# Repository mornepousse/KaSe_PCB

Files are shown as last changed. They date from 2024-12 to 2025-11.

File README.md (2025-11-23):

# KaSe – Keyboard Dev Kit

This repository contains the KiCad project and resources for the KaSe keyboard, a compact, column-staggered layout inspired by the Atreus62.

## Project overview

KaSe is designed to be:
- ergonomic, with a compact and column-oriented layout;
- DIY‑friendly, using a single PCB and common components;
- easy to customize (firmware, keymap, and hardware variations).

## Photos

### Main view

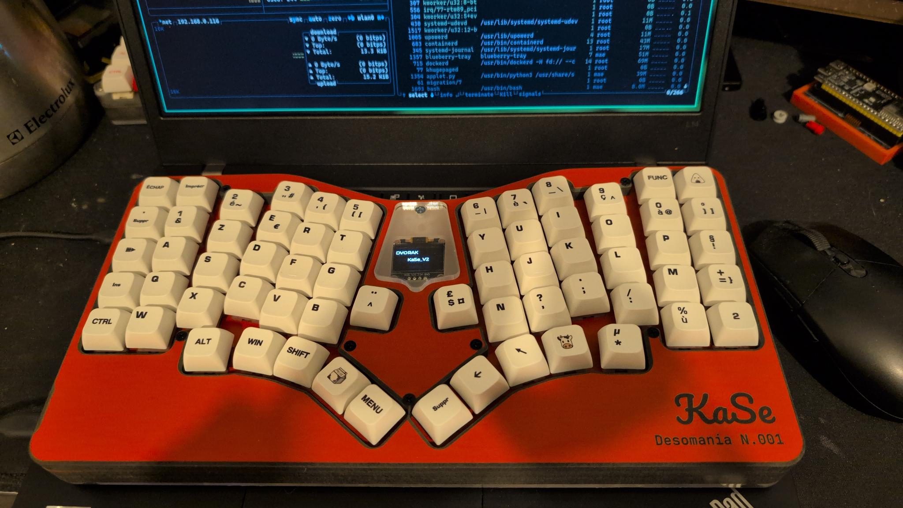
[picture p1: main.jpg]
Main view


Assembled KaSe keyboard with switches and keycaps installed. This picture gives an overview of the final form factor and layout.

### Top view – PCB

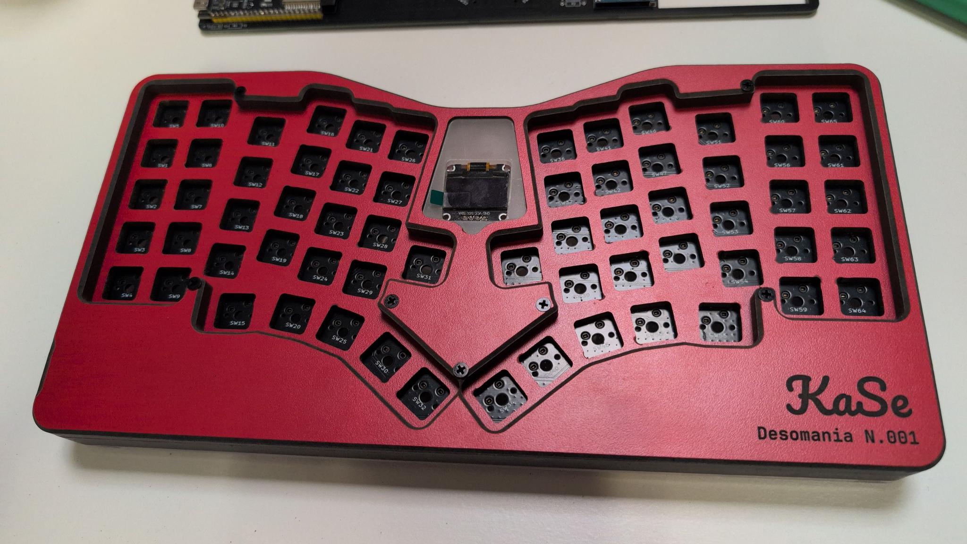
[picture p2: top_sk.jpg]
Top view


Top‑side view of the PCB showing:
- board outline,
- switch positions,
- locations of main components and connectors.

### Routing details

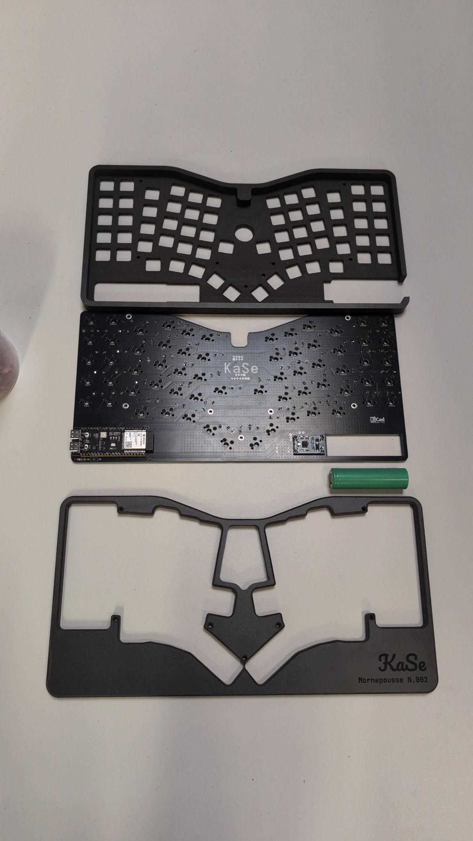
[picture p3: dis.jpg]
Routing details


Close‑up of the PCB routing, highlighting:
- main traces and vias,
- matrix rows/columns and power traces,
- silkscreen details and graphics.

### Bottom view

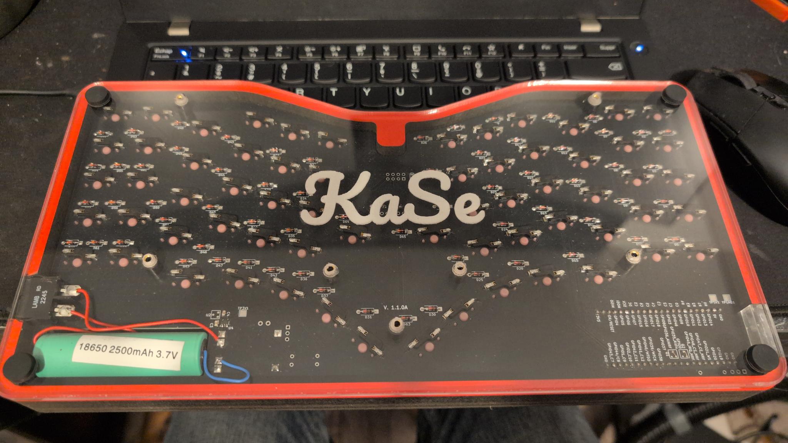
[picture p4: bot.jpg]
Bottom view


Underside of the PCB or assembly, showing:
- copper pours and ground planes,
- pads and vias,
- possible logos and fabrication information.

## Repository structure

- `Old/` – Legacy Atreus62 project kept for reference.
- `V2/KaSe/` – Current KaSe PCB KiCad project (schematic, PCB, libraries, production files).
- `V2/schematic.crv3d` – 3D/MCAD resources related to the project.
- `README.md` – Project documentation (this file).

## Main KiCad files (KaSe)

Inside `V2/KaSe/`:
- `KaSe.kicad_sch` / `KaSe.sch` – keyboard schematic.
- `KaSe.kicad_pcb` – PCB layout for KaSe.
- `Gerbers/` – production files for PCB manufacturing.
- `footprints.pretty/`, `key.pretty/`, `MaeLid.pretty/`, `PMW3360.pretty/`, `NRF24L01_/` – custom footprints and symbols used in the design.
- `KaSe.kicad_pro` / `KaSe.pro` – KiCad project files.

## Opening the project in KiCad

1. Clone the repository:
	```bash
	git clone https://github.com/mornepousse/KaSe_PCB.git
	cd KaSe_PCB
	```
2. Open KiCad.
3. Open the project file `V2/KaSe/KaSe.kicad_pro`.
4. From KiCad, open the schematic (`KaSe.kicad_sch`) and the PCB (`KaSe.kicad_pcb`).

## PCB fabrication

Gerber files for manufacturing are located in `V2/KaSe/Gerbers/`.

Typical steps:
- Zip the contents of `V2/KaSe/Gerbers/`.
- Upload the ZIP archive to your PCB manufacturer (e.g. JLCPCB).
- Check the PCB preview and confirm the order.

## License and usage

Unless otherwise specified in this repository, this project is provided for personal, experimental, and educational use.  
Please credit the original project if you publish or derive from this design.

---

# KaSe – Kit de développement de clavier

Ce dépôt contient le projet KiCad et les ressources nécessaires pour le clavier KaSe, un clavier compact à colonnes inspiré de l’Atreus62.

## Présentation du projet

Le KaSe est conçu pour être :
- ergonomique, avec une disposition compacte et en colonnes ;
- adapté au DIY, avec un seul PCB et des composants courants ;
- facilement personnalisable (firmware, disposition des touches, variantes matérielles).

## Photos

### Vue principale

Vue principale

Clavier KaSe assemblé avec les switchs et les keycaps installés. Cette photo donne une idée du format final et de la disposition.

### Vue du dessus – PCB

Vue du dessus – PCB

Vue du PCB côté composants montrant :
- le contour de la carte,
- l’implantation des switchs,
- les emplacements des principaux composants et connecteurs.

### Détails du routage

Détails du routage

Gros plan sur le routage du PCB mettant en avant :
- les pistes et vias principaux,
- les lignes du matrix (rangées/colonnes) et l’alimentation,
- les détails de sérigraphie et éléments graphiques.

### Vue du dessous

Vue du dessous

Vue de l’arrière du PCB ou de l’assemblage, montrant :
- les plans de masse et surfaces cuivrées,
- les pastilles et vias,
- les logos et informations de fabrication éventuels.

## Structure du dépôt

- `Old/` – Ancien projet Atreus62 conservé comme référence.
- `V2/KaSe/` – Projet KiCad actuel du PCB KaSe (schéma, PCB, bibliothèques, fichiers de production).
- `V2/schematic.crv3d` – Ressources 3D/CAO liées au projet.
- `README.md` – Documentation du projet (ce fichier).

## Fichiers KiCad principaux (KaSe)

Dans `V2/KaSe/` :
- `KaSe.kicad_sch` / `KaSe.sch` – schémas du clavier.
- `KaSe.kicad_pcb` – routage du PCB KaSe.
- `Gerbers/` – fichiers de production pour la fabrication du PCB.
- `footprints.pretty/`, `key.pretty/`, `MaeLid.pretty/`, `PMW3360.pretty/`, `NRF24L01_/` – bibliothèques de footprints et symboles spécifiques.
- `KaSe.kicad_pro` / `KaSe.pro` – fichiers de projet KiCad.

## Ouvrir le projet dans KiCad

1. Cloner le dépôt :
	```bash
	git clone https://github.com/mornepousse/KaSe_PCB.git
	cd KaSe_PCB
	```
2. Ouvrir KiCad.
3. Charger le projet `V2/KaSe/KaSe.kicad_pro`.
4. Depuis KiCad, ouvrir le schéma (`KaSe.kicad_sch`) puis le PCB (`KaSe.kicad_pcb`).

## Fabrication du PCB

Les fichiers Gerber sont dans `V2/KaSe/Gerbers/`.

Étapes typiques :
- Compresser le contenu de `V2/KaSe/Gerbers/` dans une archive `.zip`.
- Importer cette archive sur le site de ton fabricant de PCB (par ex. JLCPCB).
- Vérifier la prévisualisation puis valider la commande.

## Licence et utilisation

Sauf indication contraire dans ce dépôt, ce projet est fourni pour un usage personnel, expérimental et éducatif.  
Merci de mentionner la source si tu republies ou dérives ce design.

Mae Keyboard DEV Kit version

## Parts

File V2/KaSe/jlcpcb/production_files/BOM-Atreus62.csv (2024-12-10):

Comment | Designator | Footprint | LCSC
10K | R15,R16,R17,R18,R20,R4,R5,R6 | R_0402_1005Metric | C11702
100nF | C15,C2,C5,C6,C8 | C_0402_1005Metric | C1525
TPS63031DSK | U9 | WSON-10-1EP_2.5x2.5mm_P0.5mm_EP1.2x2mm | C15516
1uF | C1,C10,C11,C12,C19,C20,C22,C28,C3,C4,C7,C9 | C_0402_1005Metric | C15525
22pF | C13,C14 | C_0402_1005Metric | C1555
680K | R1 | R_0402_1005Metric | C158991
150K | R9 | R_0603_1608Metric_Pad0.98x0.95mm_HandSolder | C22807
220K | R8 | R_0603_1608Metric_Pad0.98x0.95mm_HandSolder | C22961
GREEN | LED1 | LED_0805_2012Metric | C2297
470K | R10,R11 | R_0603_1608Metric_Pad0.98x0.95mm_HandSolder | C23178
4.7uF | C17,C27 | C_0402_1005Metric | C23733
22 | R14,R2,R3,R7 | R_0402_1005Metric | C25092
5k1 | R12,R13 | R_0402_1005Metric | C25905
40MHz | Y1 | Crystal_SMD_3225-4Pin_3.2x2.5mm | C2875582
BQ25611D | U1 | Texas_RTW_WQFN-24-1EP_4x4mm_P0.5mm_EP2.7x2.7mm_ThermalVias | C2892871
ESP32-S3 | U2 | QFN-56-1EP_7x7mm_P0.4mm_EP5.6x5.6mm | C2913194
USB_C_Plug_USB2.0 | P1 | USB_C_Receptacle_GCT_USB4105-xx-A_16P_TopMnt_Horizontal | C2936185
10pF | C16,C18 | C_0402_1005Metric | C32949
Antenna_Shield | AE2 | ipx | C496552
1.5 μH | L1,L2 | L_Cenker_CKCS3012 | C75110
DIODE | D1,D10,D11,D12,D13,D14,D15,D16,D17,D18,D19,D2,D20,D21,D22,D23,D24,D25,D26,D27,D28,D29,D3,D30,D31,D33,D34,D35,D36,D37,D38,D39,D4,D40,D41,D42,D43,D44,D45,D46,D47,D48,D49,D5,D50,D51,D52,D53,D54,D55,D56,D57,D58,D59,D6,D60,D61,D62,D63,D64,D65,D7,D8,D9 | D_SOD-123 | C8598
W25Q128JVS | U4 | SOIC-8_5.23x5.23mm_P1.27mm | C97521
1nH | L3 | R_0402_1005Metric | C97981
Conn_01x10_Pin | J4 | PinSocket_2x05_P1.27mm_Vertical
TestPoint_Loop_D3.80mm_Drill2.8mm | HS8 | TestPoint_Loop_D3.80mm_Drill2.8mm
SWITCH_PUSH | SW61 | SW_Cherry_MX_1.00u_PCB
SWITCH_PUSH | SW50 | SW_Cherry_MX_1.00u_PCB
SWITCH_PUSH | SW21 | SW_Cherry_MX_1.00u_PCB
TestPoint_Loop_D3.80mm_Drill2.8mm | HS7 | TestPoint_Loop_D3.80mm_Drill2.8mm
Conn_01x10_Pin | J2 | PinHeader_2x05_P2.54mm_Vertical
SWITCH_PUSH | SW63 | SW_Cherry_MX_1.00u_PCB
SWITCH_PUSH | SW64 | SW_Cherry_MX_1.00u_PCB
SWITCH_PUSH | SW7 | SW_Cherry_MX_1.00u_PCB
SWITCH_PUSH | SW60 | SW_Cherry_MX_1.00u_PCB
SWITCH_PUSH | SW55 | SW_Cherry_MX_1.00u_PCB
SWITCH_PUSH | SW9 | SW_Cherry_MX_1.00u_PCB
SWITCH_PUSH | SW17 | SW_Cherry_MX_1.00u_PCB
SWITCH_PUSH | SW10 | SW_Cherry_MX_1.00u_PCB
TestPoint_Loop_D3.80mm_Drill2.8mm | HS2 | TestPoint_Loop_D3.80mm_Drill2.8mm
SWITCH_PUSH | SW51 | SW_Cherry_MX_1.00u_PCB
SWITCH_PUSH | SW65 | SW_Cherry_MX_1.00u_PCB
SWITCH_PUSH | SW38 | SW_Cherry_MX_1.00u_PCB
Conn_01x02 | J1 | D_T-1_P2.54mm_Vertical_AnodeUp
SWITCH_PUSH | SW25 | SW_Cherry_MX_1.00u_PCB
SWITCH_PUSH | SW23 | SW_Cherry_MX_1.00u_PCB
TestPoint_Loop_D3.80mm_Drill2.8mm | HS3 | TestPoint_Loop_D3.80mm_Drill2.8mm
SWITCH_PUSH | SW48 | SW_Cherry_MX_1.00u_PCB
TestPoint_Loop_D3.80mm_Drill2.8mm | HS5 | TestPoint_Loop_D3.80mm_Drill2.8mm
SWITCH_PUSH | SW14 | SW_Cherry_MX_1.00u_PCB
SWITCH_PUSH | SW52 | SW_Cherry_MX_1.00u_PCB
SWITCH_PUSH | SW62 | SW_Cherry_MX_1.00u_PCB
SWITCH_PUSH | SW54 | SW_Cherry_MX_1.00u_PCB
SWITCH_PUSH | SW24 | SW_Cherry_MX_1.00u_PCB
TestPoint_Loop_D3.80mm_Drill2.8mm | HS1 | TestPoint_Loop_D3.80mm_Drill2.8mm
SWITCH_PUSH | SW45 | SW_Cherry_MX_1.00u_PCB
SWITCH_PUSH | SW37 | SW_Cherry_MX_1.00u_PCB
SWITCH_PUSH | SW56 | SW_Cherry_MX_1.00u_PCB
SWITCH_PUSH | SW53 | SW_Cherry_MX_1.00u_PCB
SWITCH_PUSH | SW28 | SW_Cherry_MX_1.00u_PCB
SWITCH_PUSH | SW8 | SW_Cherry_MX_1.00u_PCB
SWITCH_PUSH | SW22 | SW_Cherry_MX_1.00u_PCB
TestPoint_Loop_D3.80mm_Drill2.8mm | HS6 | TestPoint_Loop_D3.80mm_Drill2.8mm
SWITCH_PUSH | SW19 | SW_Cherry_MX_1.00u_PCB
SWITCH_PUSH | SW13 | SW_Cherry_MX_1.00u_PCB
SWITCH_PUSH | SW2 | SW_Cherry_MX_1.00u_PCB
SWITCH_PUSH | SW43 | SW_Cherry_MX_1.00u_PCB
SWITCH_PUSH | SW57 | SW_Cherry_MX_1.00u_PCB
SWITCH_PUSH | SW1 | SW_Cherry_MX_1.00u_PCB
SWITCH_PUSH | SW29 | SW_Cherry_MX_1.00u_PCB
SWITCH_PUSH | SW42 | SW_Cherry_MX_1.00u_PCB
SWITCH_PUSH | SW49 | SW_Cherry_MX_1.00u_PCB
SWITCH_PUSH | SW44 | SW_Cherry_MX_1.00u_PCB
SWITCH_PUSH | SW18 | SW_Cherry_MX_1.00u_PCB
kicad | HS9 | KiCad-Logo2_5mm_SilkScreen
SWITCH_PUSH | SW11 | SW_Cherry_MX_1.00u_PCB
SWITCH_PUSH | SW58 | SW_Cherry_MX_1.00u_PCB
SWITCH_PUSH | SW32 | SW_Cherry_MX_1.00u_PCB
SWITCH_PUSH | SW15 | SW_Cherry_MX_1.00u_PCB
SWITCH_PUSH | SW39 | SW_Cherry_MX_1.00u_PCB
SWITCH_PUSH | SW33 | SW_Cherry_MX_1.00u_PCB
SWITCH_PUSH | SW41 | SW_Cherry_MX_1.00u_PCB
SWITCH_PUSH | SW20 | SW_Cherry_MX_1.00u_PCB
SWITCH_PUSH | SW5 | SW_Cherry_MX_1.00u_PCB
SWITCH_PUSH | SW59 | SW_Cherry_MX_1.00u_PCB
SWITCH_PUSH | SW6 | SW_Cherry_MX_1.00u_PCB
SWITCH_PUSH | SW27 | SW_Cherry_MX_1.00u_PCB
SWITCH_PUSH | SW16 | SW_Cherry_MX_1.00u_PCB
SWITCH_PUSH | SW40 | SW_Cherry_MX_1.00u_PCB
SWITCH_PUSH | SW47 | SW_Cherry_MX_1.00u_PCB
SWITCH_PUSH | SW46 | SW_Cherry_MX_1.00u_PCB
SWITCH_PUSH | SW34 | SW_Cherry_MX_1.00u_PCB
SWITCH_PUSH | SW26 | SW_Cherry_MX_1.00u_PCB
Conn_02x04 | J3 | PinHeader_2x04_P2.54mm_Vertical
SWITCH_PUSH | SW36 | SW_Cherry_MX_1.00u_PCB
SWITCH_PUSH | SW30 | SW_Cherry_MX_1.00u_PCB
SWITCH_PUSH | SW31 | SW_Cherry_MX_1.00u_PCB
SWITCH_PUSH | SW4 | SW_Cherry_MX_1.00u_PCB
SWITCH_PUSH | SW12 | SW_Cherry_MX_1.00u_PCB
SWITCH_PUSH | SW3 | SW_Cherry_MX_1.00u_PCB
SERLINK | X1 | CON_SER9
TestPoint | TP1 | TestPoint_Pad_D1.0mm
Conn_02x03 | J5 | PinSocket_2x03_P1.27mm_Vertical

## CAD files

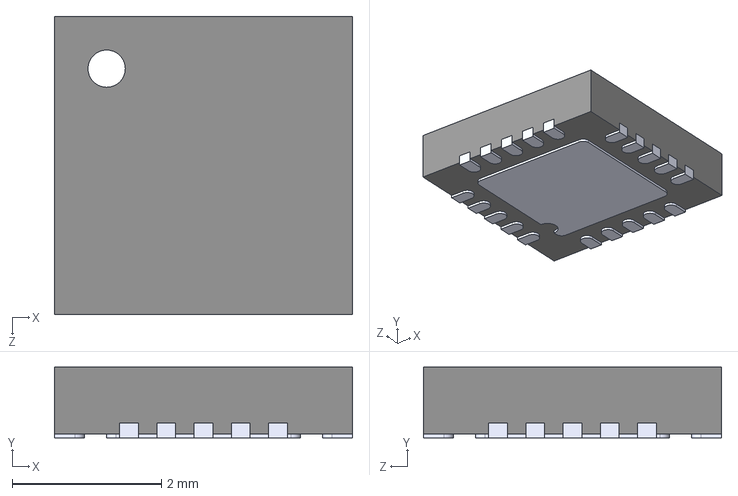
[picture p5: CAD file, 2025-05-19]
Mae_Keyboard_Dev_Kit/NRF24L01_/NRF24L01_.step
4.00 x 0.95 x 4.00 mm

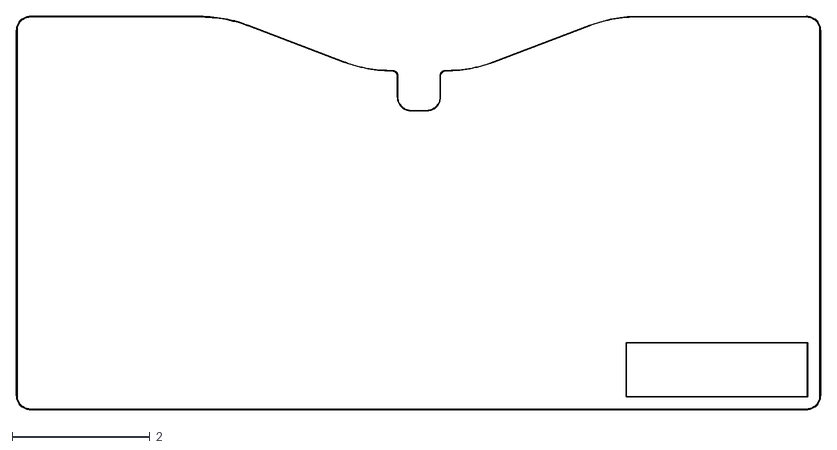
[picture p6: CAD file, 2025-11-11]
V2/KaSe/DXF/KaSe-Edge_Cuts.dxf
11.7 x 5.72

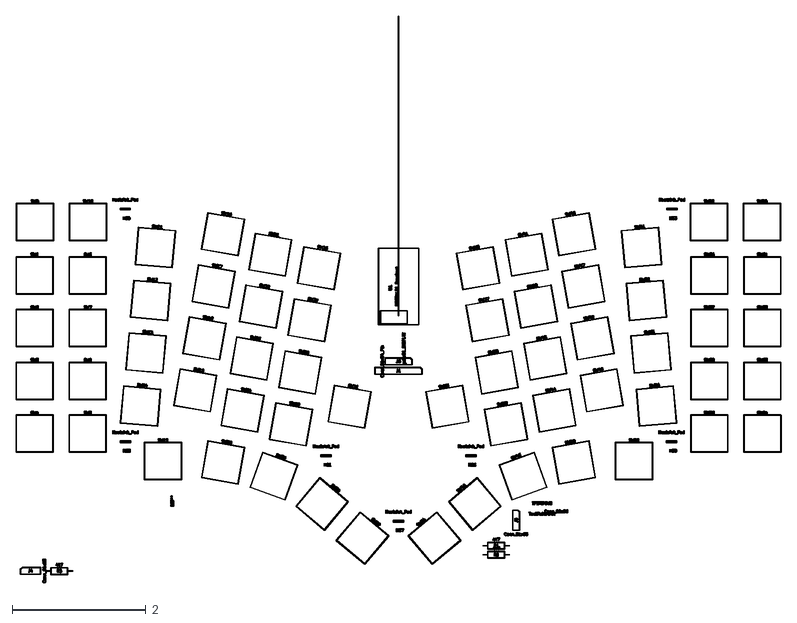
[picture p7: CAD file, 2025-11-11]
V2/KaSe/DXF/KaSe-F_Fab.dxf
11.4 x 8.45

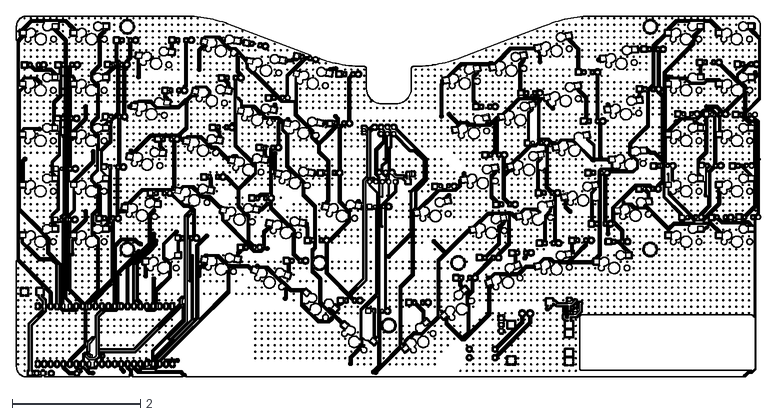
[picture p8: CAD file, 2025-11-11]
V2/KaSe/DXF/KaSe-B_Cu.dxf
11.6 x 5.63

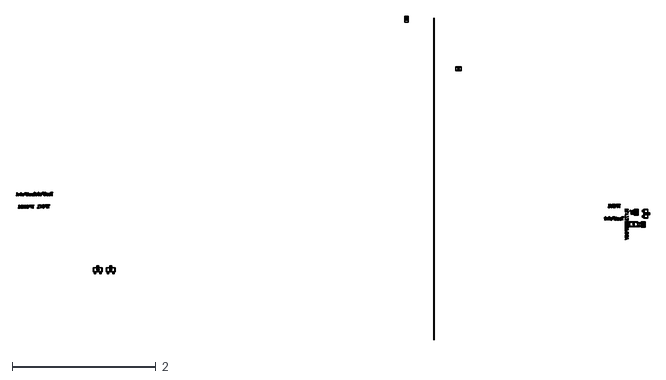
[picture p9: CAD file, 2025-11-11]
V2/KaSe/DXF/KaSe-B_Fab.dxf
8.82 x 4.50

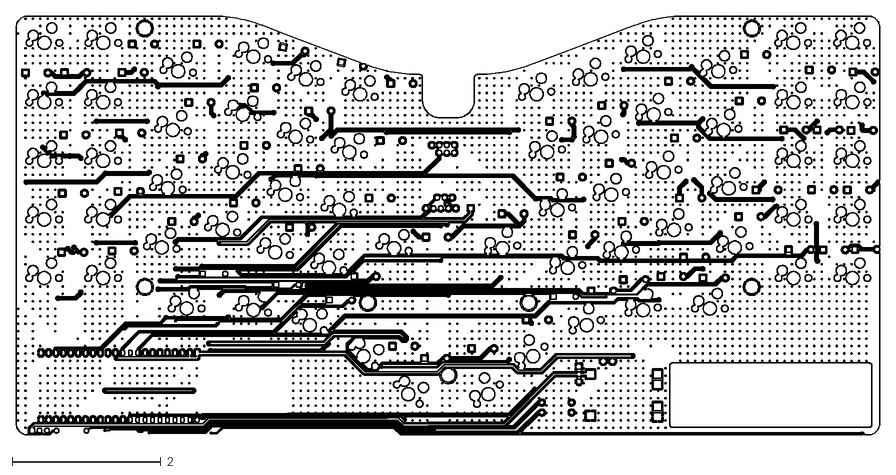
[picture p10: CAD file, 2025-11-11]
V2/KaSe/DXF/KaSe-F_Cu.dxf
11.6 x 5.63

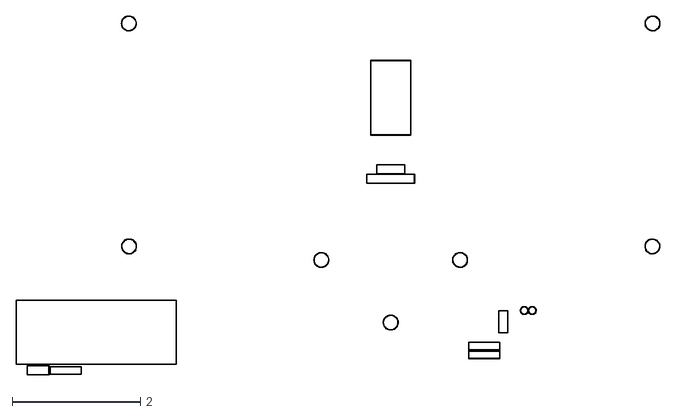
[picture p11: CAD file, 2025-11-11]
V2/KaSe/DXF/KaSe-F_Courtyard.dxf
10.0 x 5.59

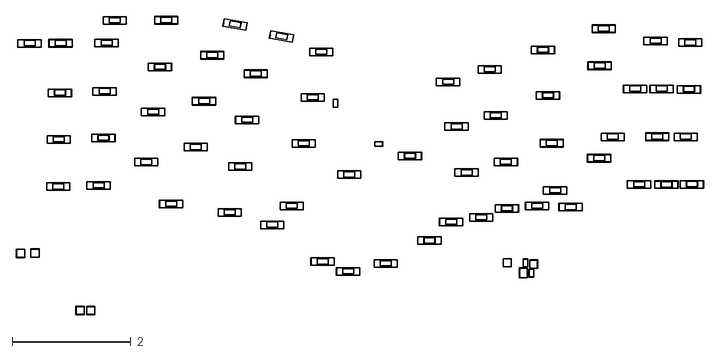
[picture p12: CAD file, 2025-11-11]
V2/KaSe/DXF/KaSe-B_Courtyard.dxf
11.6 x 5.01

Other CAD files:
V2/KaSe/DXF/KaSe-F_Adhesive.dxf
V2/KaSe/DXF/KaSe-B_Adhesive.dxf
V2/KaSe/DXF/KaSe-B_Mask.dxf
V2/KaSe/DXF/KaSe-B_Paste.dxf
V2/KaSe/DXF/KaSe-B_Silkscreen.dxf
V2/KaSe/DXF/KaSe-F_Mask.dxf
V2/KaSe/DXF/KaSe-F_Paste.dxf
V2/KaSe/DXF/KaSe-F_Silkscreen.dxf

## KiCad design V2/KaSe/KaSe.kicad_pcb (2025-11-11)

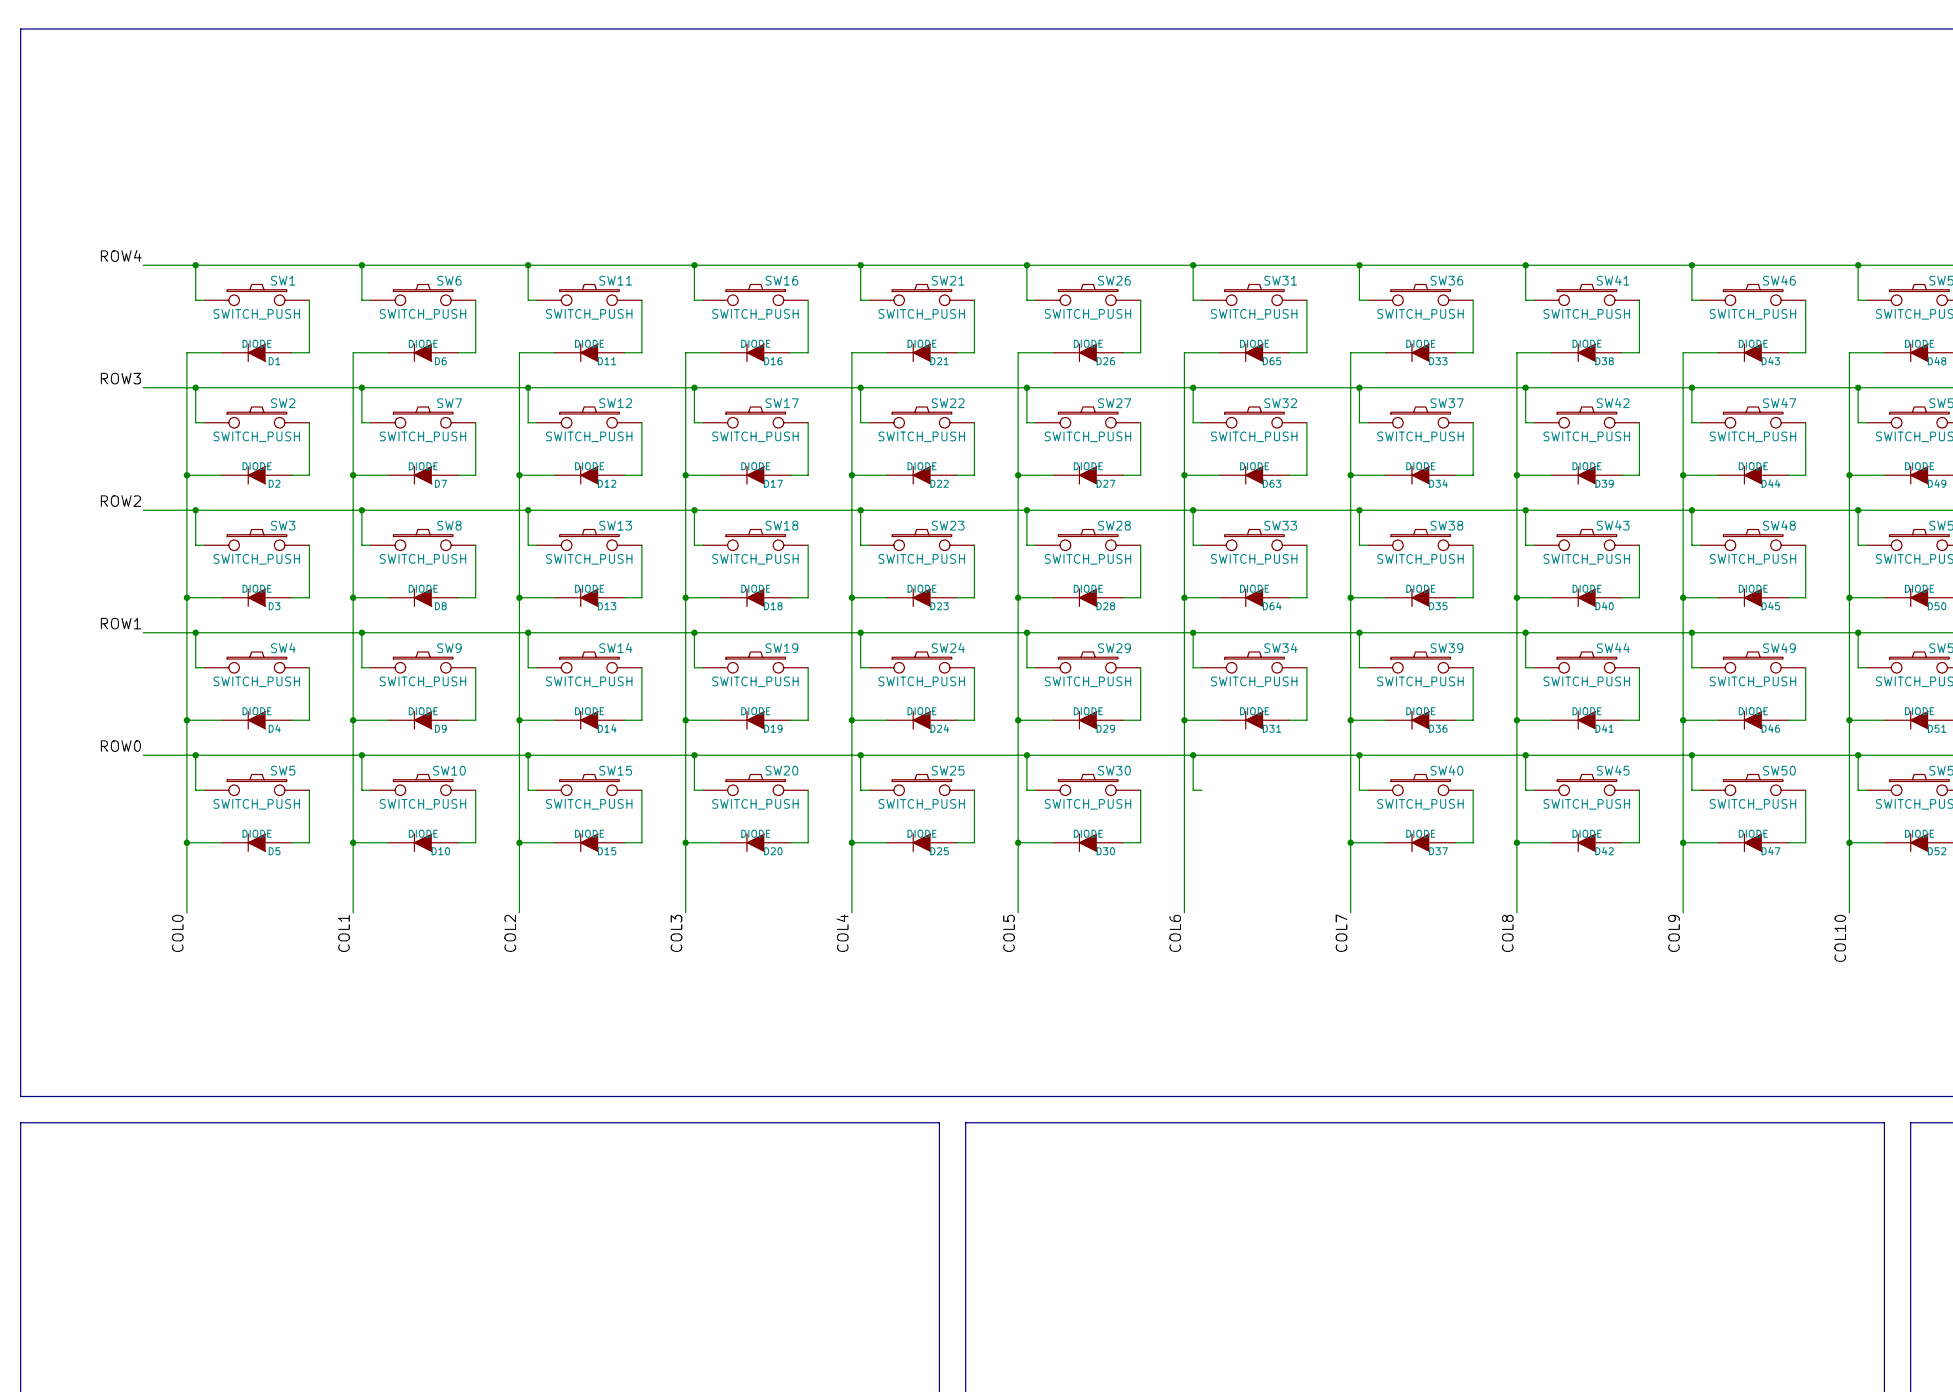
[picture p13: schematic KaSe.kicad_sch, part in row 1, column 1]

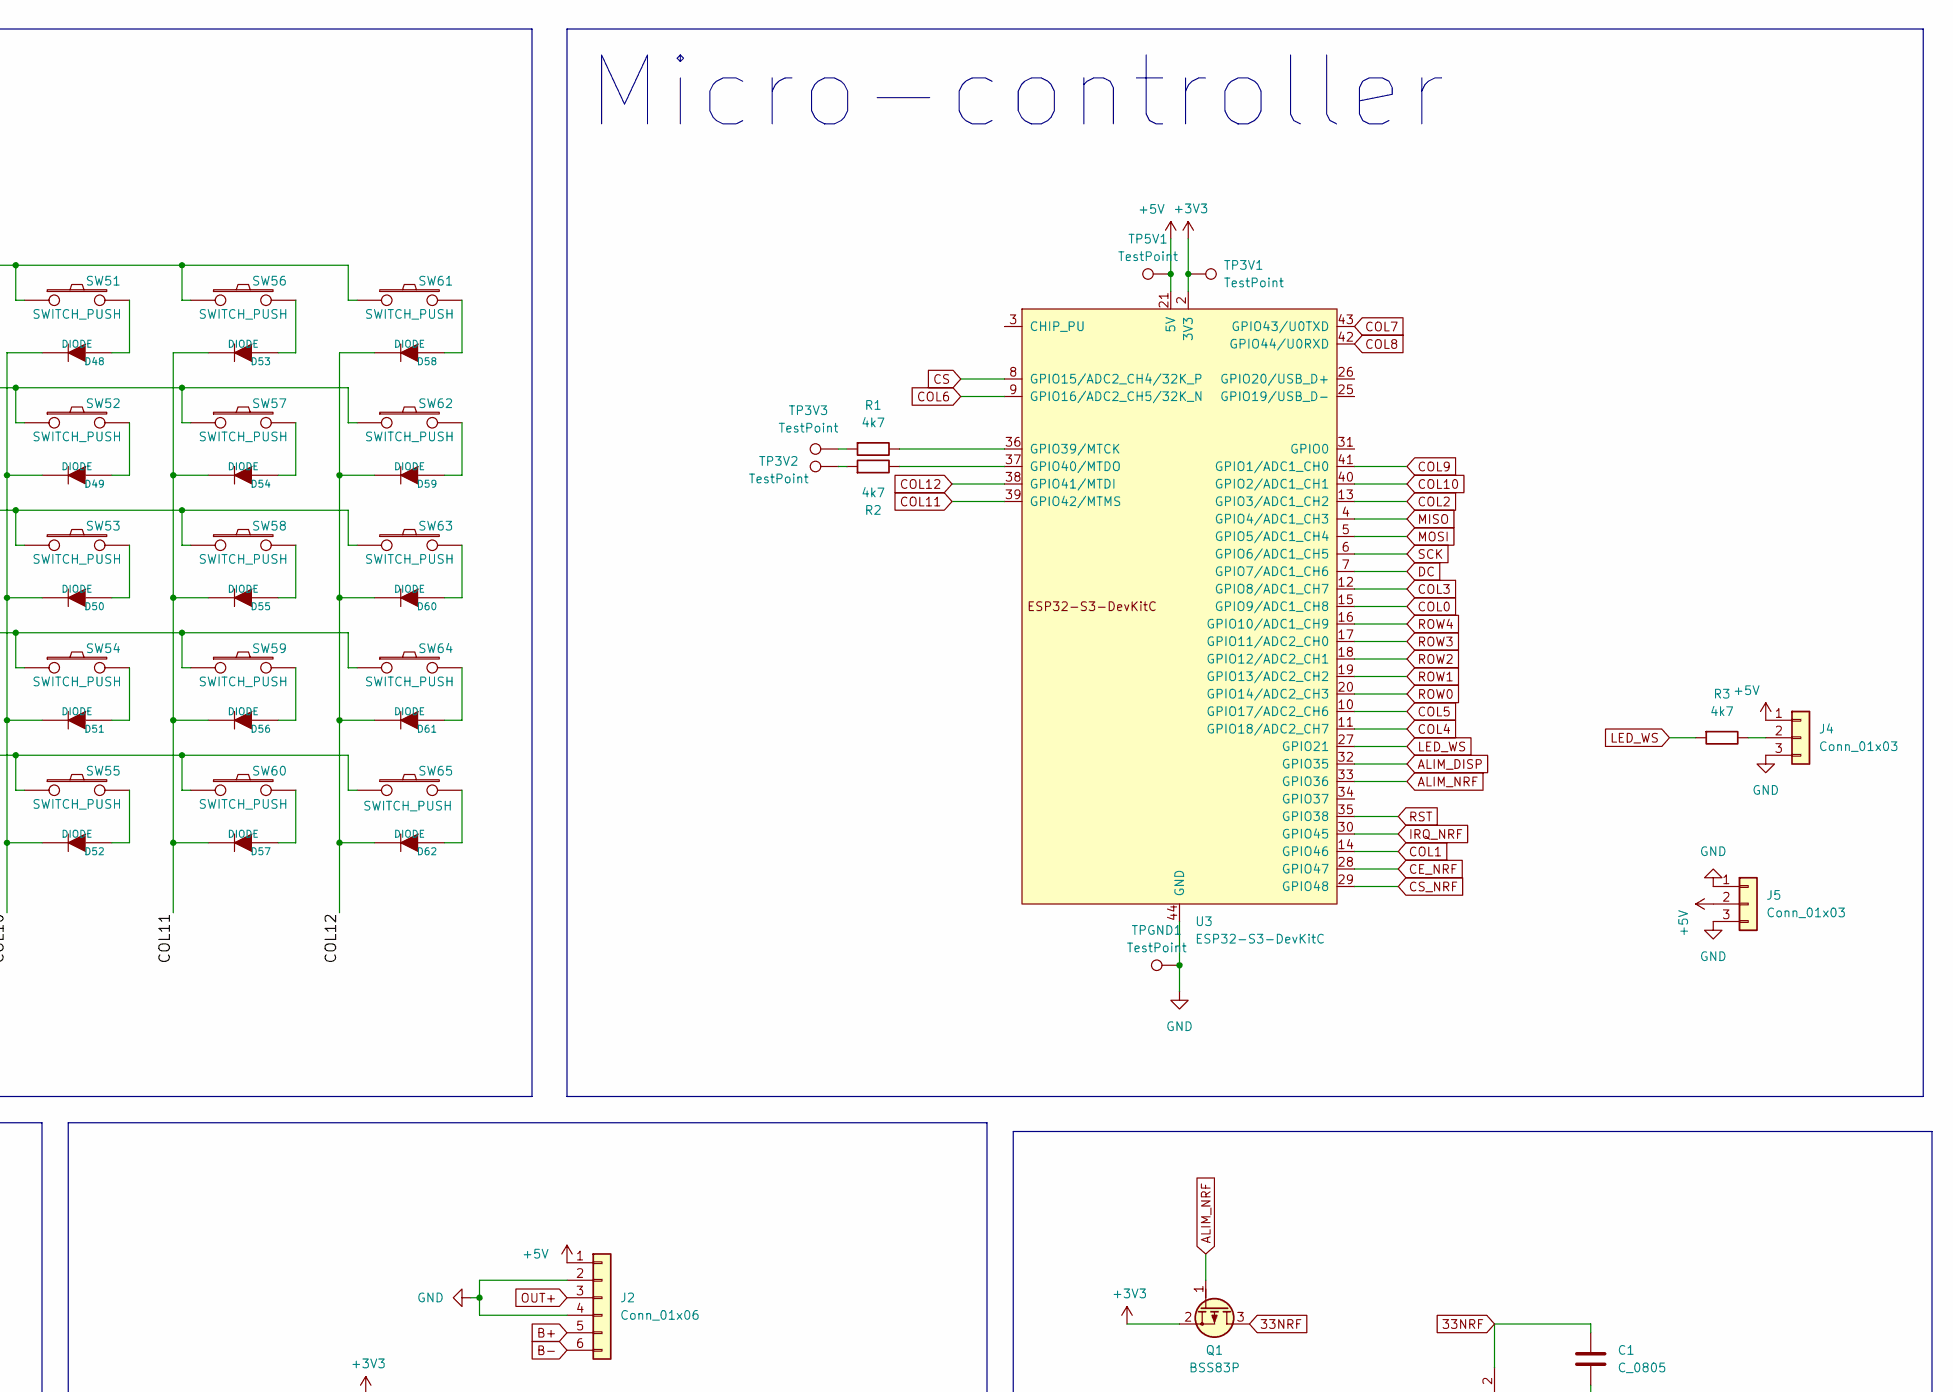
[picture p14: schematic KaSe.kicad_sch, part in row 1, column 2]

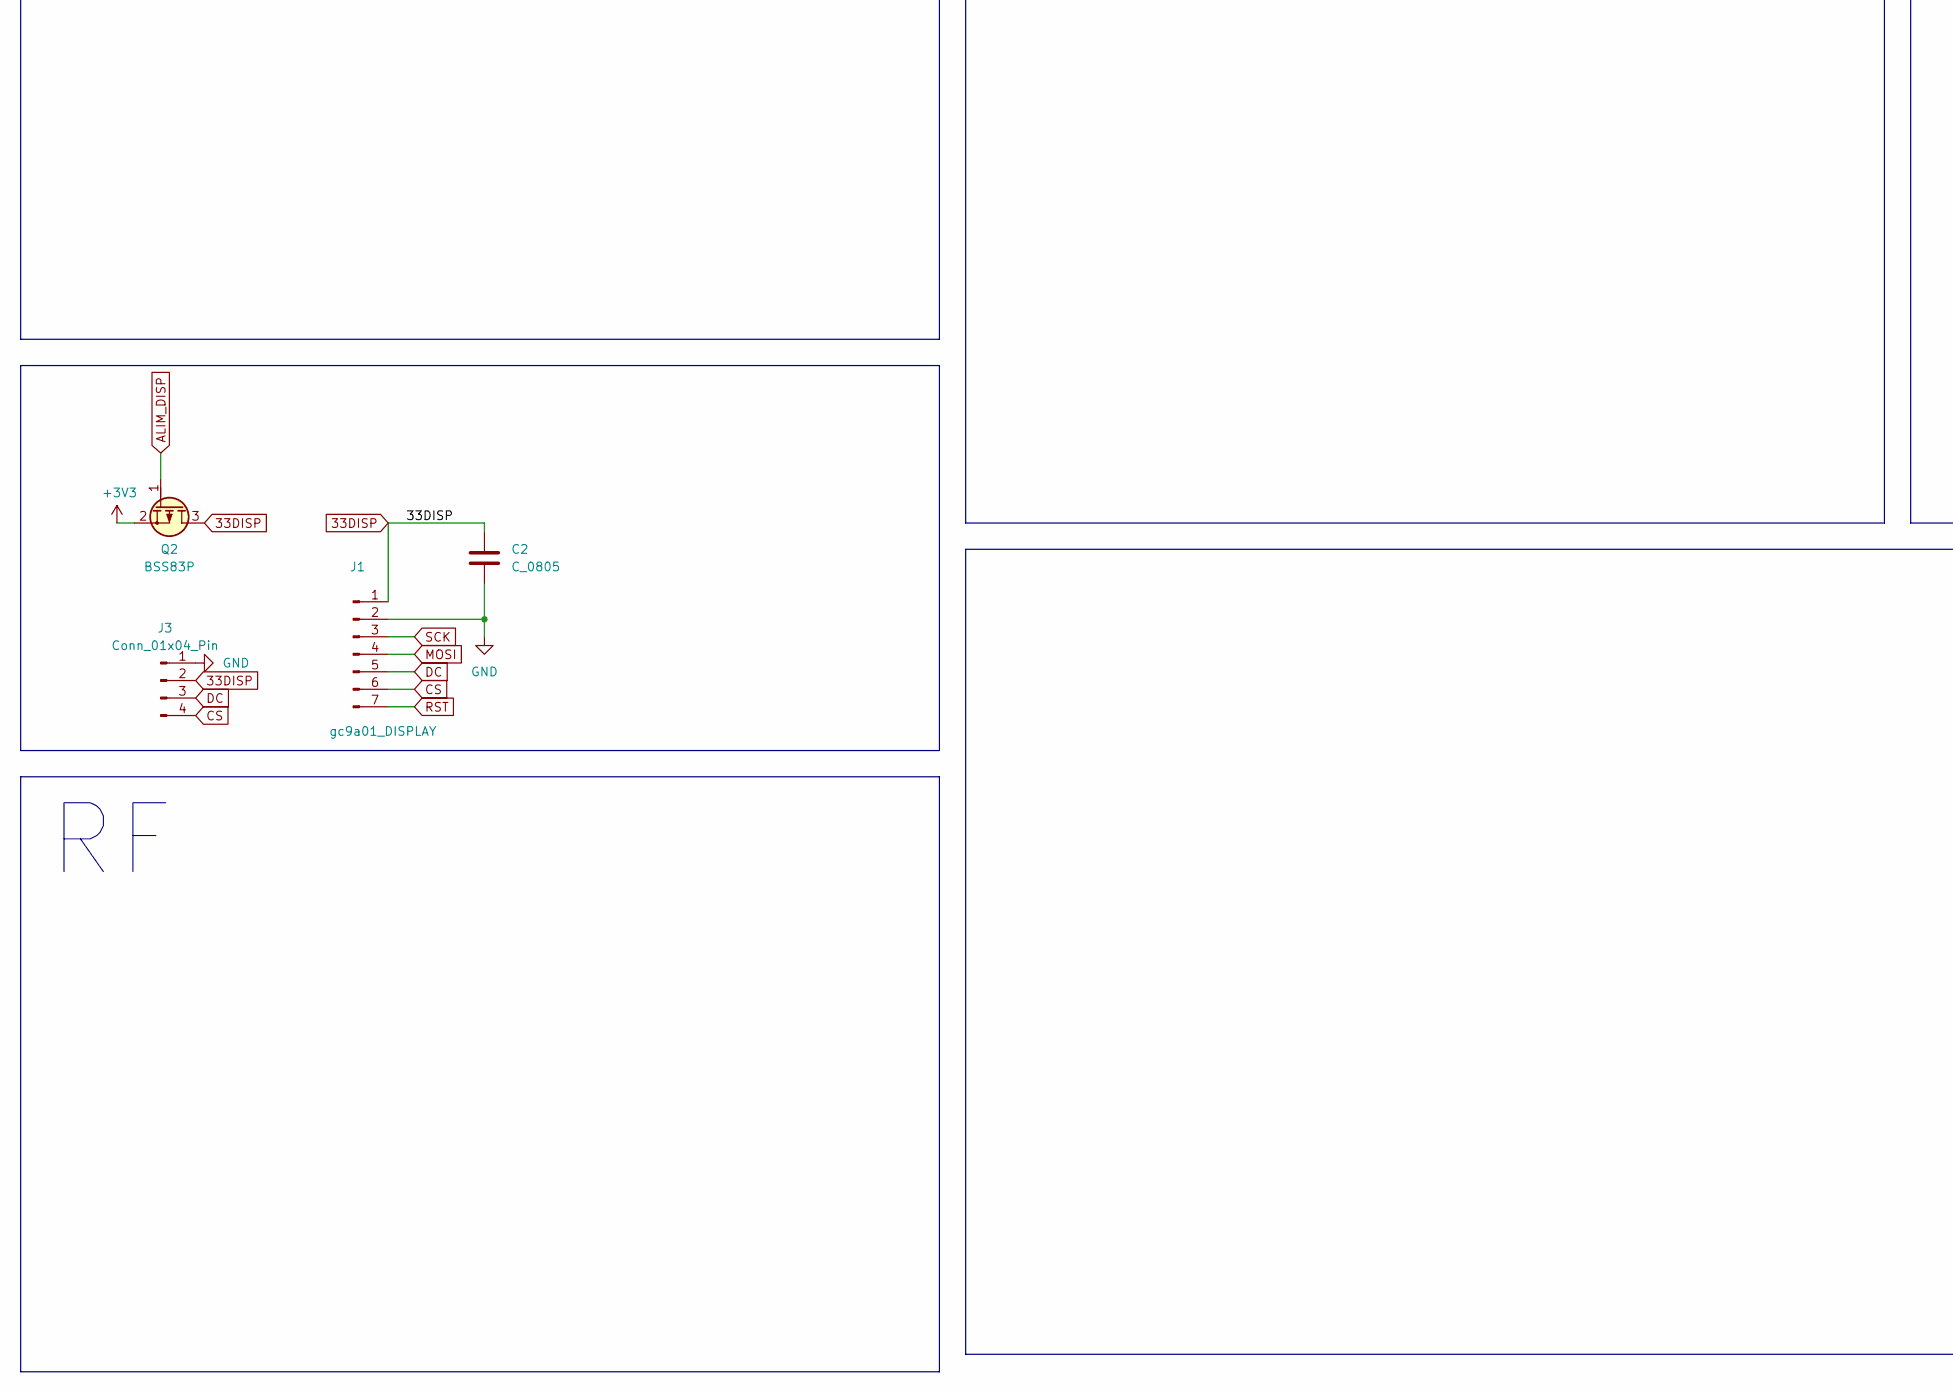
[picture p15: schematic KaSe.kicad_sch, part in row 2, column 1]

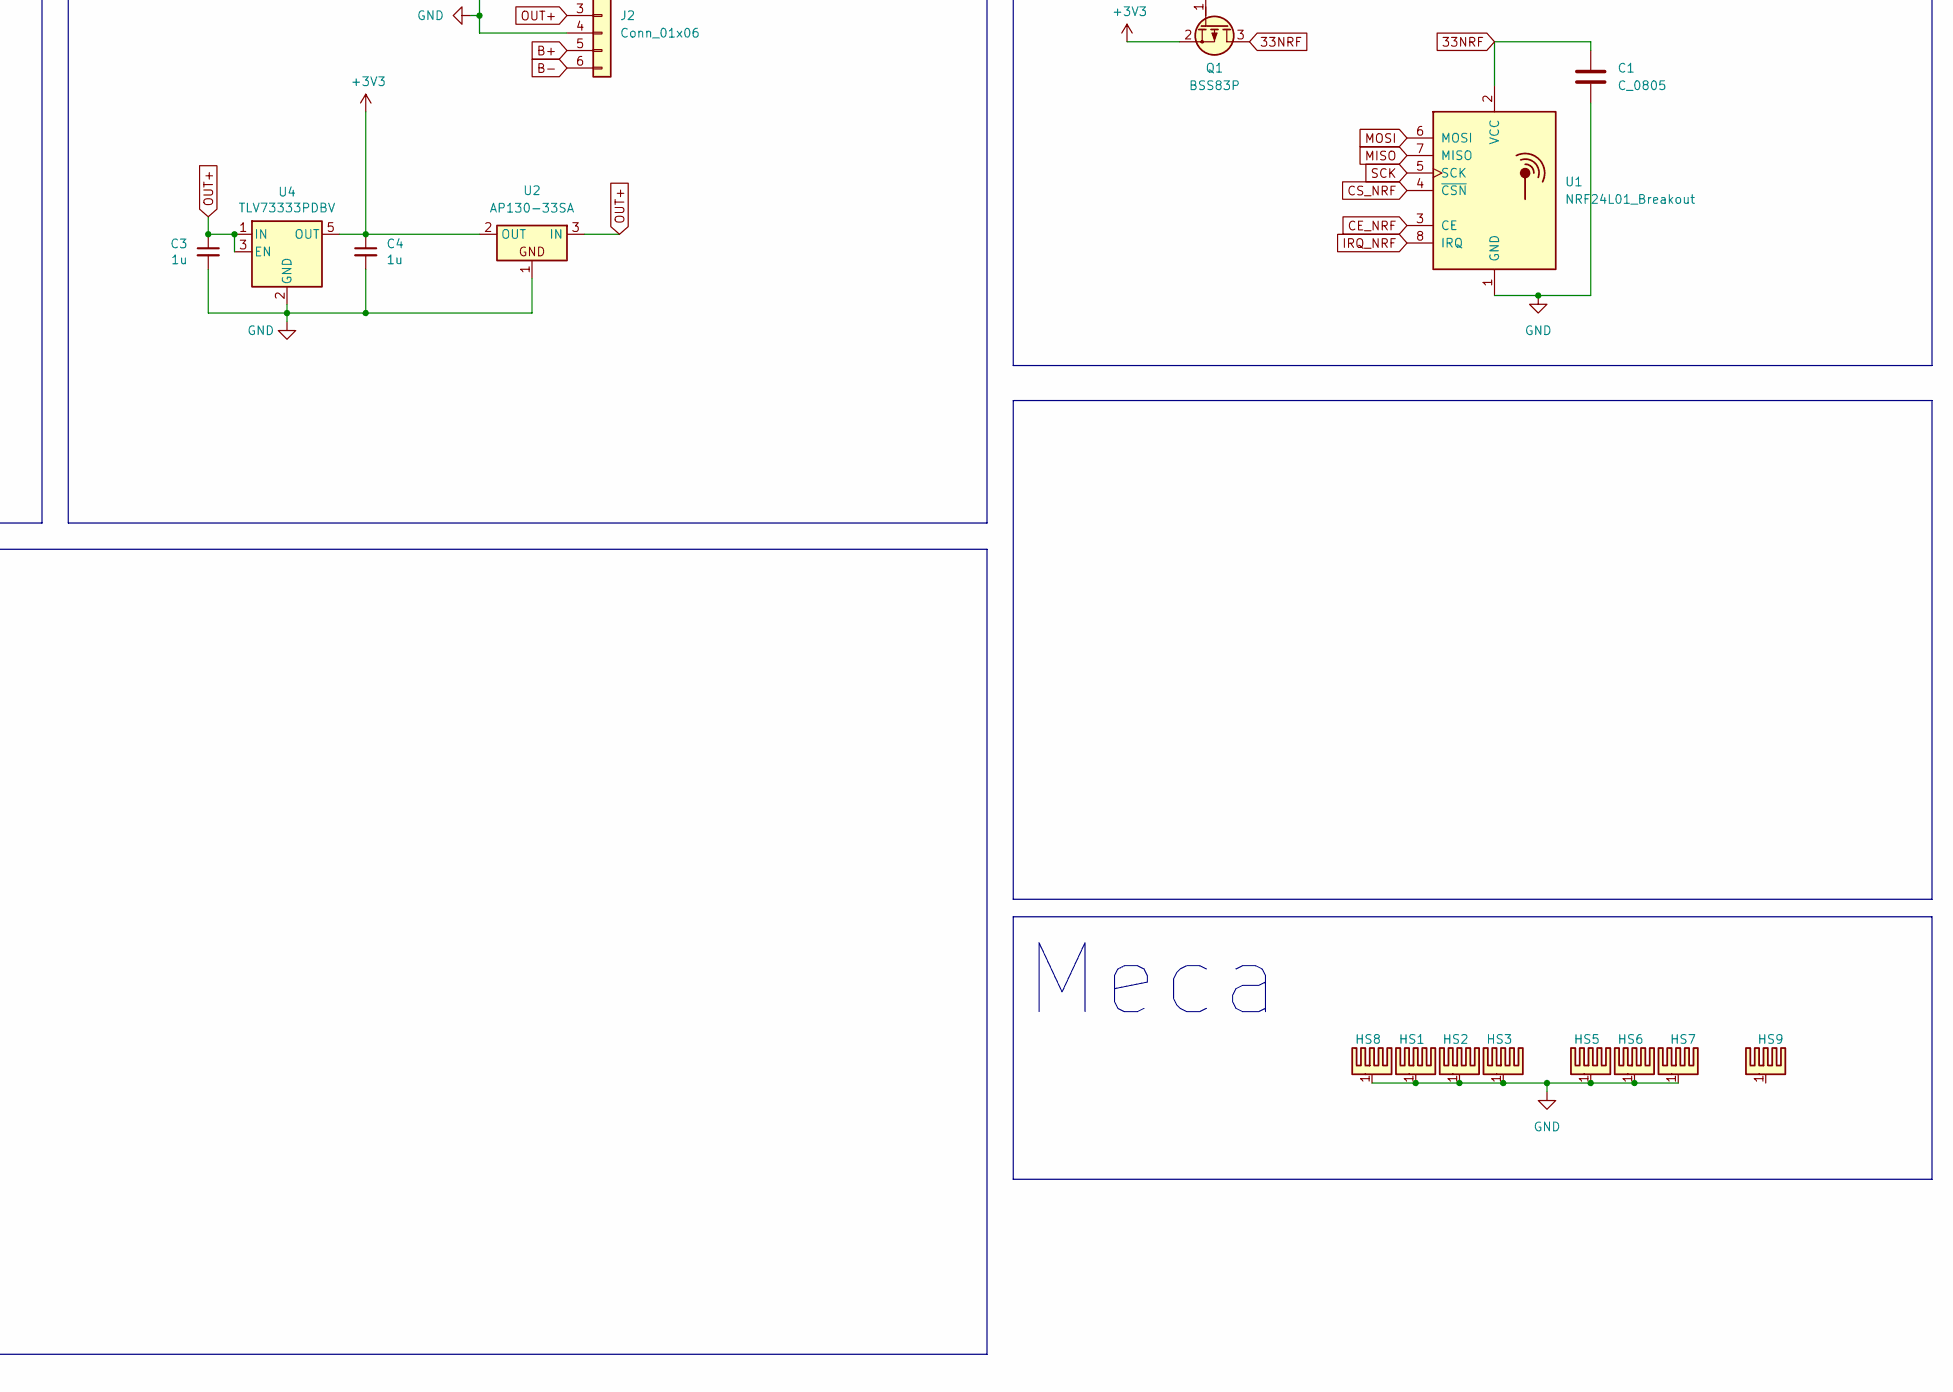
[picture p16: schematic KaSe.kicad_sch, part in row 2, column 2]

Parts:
C1, C2: C_0805; C_0805_2012Metric
C3, C4: 1u; C_0805_2012Metric; LCSC C52923
D1, D2, D3, D4, D5, D6, D7, D8, D9, D10, D11, D12, D13, D14, D15, D16, D17, D18, D19, D20, D21, D22, D23, D24, D25, D26, D27, D28, D29, D30, D31, D33, D34, D35, D36, D37, D38, D39, D40, D41, D42, D43, D44, D45, D46, D47, D48, D49, D50, D51, D52, D53, D54, D55, D56, D57, D58, D59, D60, D61, D62, D63, D64, D65: DIODE; D_SOD-123; JLCPCB_Parts C8598
HS1, HS2, HS3, HS5, HS6, HS7, HS8: Heatsink_Pad; TestPoint_Loop_D3.80mm_Drill2.8mm
HS9: kicad; KiCad-Logo2_5mm_SilkScreen
J1: gc9a01_DISPLAY; PinHeader_1x07_P2.54mm_Vertical
J2: Conn_01x06; TP4056-18650
J3: Conn_01x04_Pin; PinHeader_1x04_P2.54mm_Vertical
J4, J5: Conn_01x03; PinSocket_1x03_P2.54mm_Vertical
Q1, Q2: BSS83P; SOT-23
R1, R2, R3: 4k7; R_Axial_DIN0207_L6.3mm_D2.5mm_P10.16mm_Horizontal
SW1, SW2, SW3, SW4, SW5, SW6, SW7, SW8, SW9, SW10, SW11, SW12, SW13, SW14, SW15, SW16, SW17, SW18, SW19, SW20, SW21, SW22, SW23, SW24, SW25, SW26, SW27, SW28, SW29, SW30, SW31, SW32, SW33, SW34, SW36, SW37, SW38, SW39, SW40, SW41, SW42, SW43, SW44, SW45, SW46, SW47, SW48, SW49, SW50, SW51, SW52, SW53, SW54, SW55, SW56, SW57, SW58, SW59, SW60, SW61, SW62, SW63, SW64, SW65: SWITCH_PUSH; SW_Cherry_MX_1.00u_PCB
TP3V1, TP5V1: TestPoint; TestPoint_Pad_2.5x2.5mm
TP3V2, TP3V3: TestPoint; TestPoint_THTPad_D2.0mm_Drill1.0mm
TPGND1: TestPoint; TestPoint_Pad_2.5x2.5mm
U1: NRF24L01_Breakout; nRF24L01_Breakout
U2: AP130-33SA; SOT-23
U3: ESP32-S3-DevKitC
U4: TLV73333PDBV; SOT-23-5; LCSC C134139

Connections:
33DISP: C2.1, J1.1, J3.2, Q2.3 (D)
33NRF: C1.1, Q1.3 (D), U1.2 (VCC)
+3V3: C4.1, Q1.2 (S), Q2.2 (S), TP3V1.1, U2.2 (OUT), U3.1 (3V3), U3.2 (3V3), U4.5 (OUT)
+5V: J2.1, J4.1, J5.2, TP5V1.1, U3.21 (5V)
ALIM_DISP: Q2.1 (G), U3.32 (GPIO35)
ALIM_NRF: Q1.1 (G), U3.33 (GPIO36)
B+: J2.5
B-: J2.6
CE_NRF: U1.3 (CE), U3.28 (GPIO47)
COL0: D1.2 (K), D2.2 (K), D3.2 (K), D4.2 (K), D5.2 (K), U3.15 (GPIO9/ADC1_CH8)
COL1: D6.2 (K), D7.2 (K), D8.2 (K), D9.2 (K), D10.2 (K), U3.14 (GPIO46)
COL2: D11.2 (K), D12.2 (K), D13.2 (K), D14.2 (K), D15.2 (K), U3.13 (GPIO3/ADC1_CH2)
COL3: D16.2 (K), D17.2 (K), D18.2 (K), D19.2 (K), D20.2 (K), U3.12 (GPIO8/ADC1_CH7)
COL4: D21.2 (K), D22.2 (K), D23.2 (K), D24.2 (K), D25.2 (K), U3.11 (GPIO18/ADC2_CH7)
COL5: D26.2 (K), D27.2 (K), D28.2 (K), D29.2 (K), D30.2 (K), U3.10 (GPIO17/ADC2_CH6)
COL6: D31.2 (K), D63.2 (K), D64.2 (K), D65.2 (K), U3.9 (GPIO16/ADC2_CH5/32K_N)
COL7: D33.2 (K), D34.2 (K), D35.2 (K), D36.2 (K), D37.2 (K), U3.43 (GPIO43/U0TXD)
COL8: D38.2 (K), D39.2 (K), D40.2 (K), D41.2 (K), D42.2 (K), U3.42 (GPIO44/U0RXD)
COL9: D43.2 (K), D44.2 (K), D45.2 (K), D46.2 (K), D47.2 (K), U3.41 (GPIO1/ADC1_CH0)
COL10: D48.2 (K), D49.2 (K), D50.2 (K), D51.2 (K), D52.2 (K), U3.40 (GPIO2/ADC1_CH1)
COL11: D53.2 (K), D54.2 (K), D55.2 (K), D56.2 (K), D57.2 (K), U3.39 (GPIO42/MTMS)
COL12: D58.2 (K), D59.2 (K), D60.2 (K), D61.2 (K), D62.2 (K), U3.38 (GPIO41/MTDI)
CS: J1.6, J3.4, U3.8 (GPIO15/ADC2_CH4/32K_P)
CS_NRF: U1.4 (~CSN), U3.29 (GPIO48)
DC: J1.5, J3.3, U3.7 (GPIO7/ADC1_CH6)
GND: C1.2, C2.2, C3.2, C4.2, HS1.1, HS2.1, HS3.1, HS5.1, HS6.1, HS7.1, HS8.1, J1.2, J2.2, J2.4, J3.1, J4.3, J5.1, J5.3, TPGND1.1, U1.1 (GND), U2.1, U3.22 (GND), U3.23 (GND), U3.24 (GND), U3.44 (GND), U4.2 (GND)
IRQ_NRF: U1.8 (IRQ), U3.30 (GPIO45)
LED_WS: R3.1, U3.27 (GPIO21)
MISO: U1.7 (MISO), U3.4 (GPIO4/ADC1_CH3)
MOSI: J1.4, U1.6 (MOSI), U3.5 (GPIO5/ADC1_CH4)
unnamed: D1.1 (A), SW1.2
unnamed: D2.1 (A), SW2.2
unnamed: D3.1 (A), SW3.2
unnamed: D4.1 (A), SW4.2
unnamed: D5.1 (A), SW5.2
unnamed: D6.1 (A), SW6.2
unnamed: D7.1 (A), SW7.2
unnamed: D8.1 (A), SW8.2
unnamed: D9.1 (A), SW9.2
unnamed: D10.1 (A), SW10.2
unnamed: D11.1 (A), SW11.2
unnamed: D12.1 (A), SW12.2
unnamed: D13.1 (A), SW13.2
unnamed: D14.1 (A), SW14.2
unnamed: D15.1 (A), SW15.2
unnamed: D16.1 (A), SW16.2
unnamed: D17.1 (A), SW17.2
unnamed: D18.1 (A), SW18.2
unnamed: D19.1 (A), SW19.2
unnamed: D20.1 (A), SW20.2
unnamed: D21.1 (A), SW21.2
unnamed: D22.1 (A), SW22.2
unnamed: D23.1 (A), SW23.2
unnamed: D24.1 (A), SW24.2
unnamed: D25.1 (A), SW25.2
unnamed: D26.1 (A), SW26.2
unnamed: D27.1 (A), SW27.2
unnamed: D28.1 (A), SW28.2
unnamed: D29.1 (A), SW29.2
unnamed: D30.1 (A), SW30.2
unnamed: D31.1 (A), SW34.2
unnamed: D33.1 (A), SW36.2
unnamed: D34.1 (A), SW37.2
unnamed: D35.1 (A), SW38.2
unnamed: D36.1 (A), SW39.2
unnamed: D37.1 (A), SW40.2
unnamed: D38.1 (A), SW41.2
unnamed: D39.1 (A), SW42.2
unnamed: D40.1 (A), SW43.2
unnamed: D41.1 (A), SW44.2
unnamed: D42.1 (A), SW45.2
unnamed: D43.1 (A), SW46.2
unnamed: D44.1 (A), SW47.2
unnamed: D45.1 (A), SW48.2
unnamed: D46.1 (A), SW49.2
unnamed: D47.1 (A), SW50.2
unnamed: D48.1 (A), SW51.2
unnamed: D49.1 (A), SW52.2
unnamed: D50.1 (A), SW53.2
unnamed: D51.1 (A), SW54.2
unnamed: D52.1 (A), SW55.2
unnamed: D53.1 (A), SW56.2
unnamed: D54.1 (A), SW57.2
unnamed: D55.1 (A), SW58.2
unnamed: D56.1 (A), SW59.2
unnamed: D57.1 (A), SW60.2
unnamed: D58.1 (A), SW61.2
unnamed: D59.1 (A), SW62.2
unnamed: D60.1 (A), SW63.2
unnamed: D61.1 (A), SW64.2
unnamed: D62.1 (A), SW65.2
unnamed: D63.1 (A), SW32.2
unnamed: D64.1 (A), SW33.2
unnamed: D65.1 (A), SW31.2
unnamed: J4.2, R3.2
unnamed: R1.1, TP3V3.1
unnamed: R2.1, TP3V2.1
unnamed: R1.2, U3.36 (GPIO39/MTCK)
unnamed: R2.2, U3.37 (GPIO40/MTDO)
OUT+: C3.1, J2.3, U2.3 (IN), U4.1 (IN), U4.3 (EN)
ROW0: SW5.1, SW10.1, SW15.1, SW20.1, SW25.1, SW30.1, SW40.1, SW45.1, SW50.1, SW55.1, SW60.1, SW65.1, U3.20 (GPIO14/ADC2_CH3)
ROW1: SW4.1, SW9.1, SW14.1, SW19.1, SW24.1, SW29.1, SW34.1, SW39.1, SW44.1, SW49.1, SW54.1, SW59.1, SW64.1, U3.19 (GPIO13/ADC2_CH2)
ROW2: SW3.1, SW8.1, SW13.1, SW18.1, SW23.1, SW28.1, SW33.1, SW38.1, SW43.1, SW48.1, SW53.1, SW58.1, SW63.1, U3.18 (GPIO12/ADC2_CH1)
ROW3: SW2.1, SW7.1, SW12.1, SW17.1, SW22.1, SW27.1, SW32.1, SW37.1, SW42.1, SW47.1, SW52.1, SW57.1, SW62.1, U3.17 (GPIO11/ADC2_CH0)
ROW4: SW1.1, SW6.1, SW11.1, SW16.1, SW21.1, SW26.1, SW31.1, SW36.1, SW41.1, SW46.1, SW51.1, SW56.1, SW61.1, U3.16 (GPIO10/ADC1_CH9)
RST: J1.7, U3.35 (GPIO38)
SCK: J1.3, U1.5 (SCK), U3.6 (GPIO6/ADC1_CH5)

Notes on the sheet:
Meca
Micro-controller

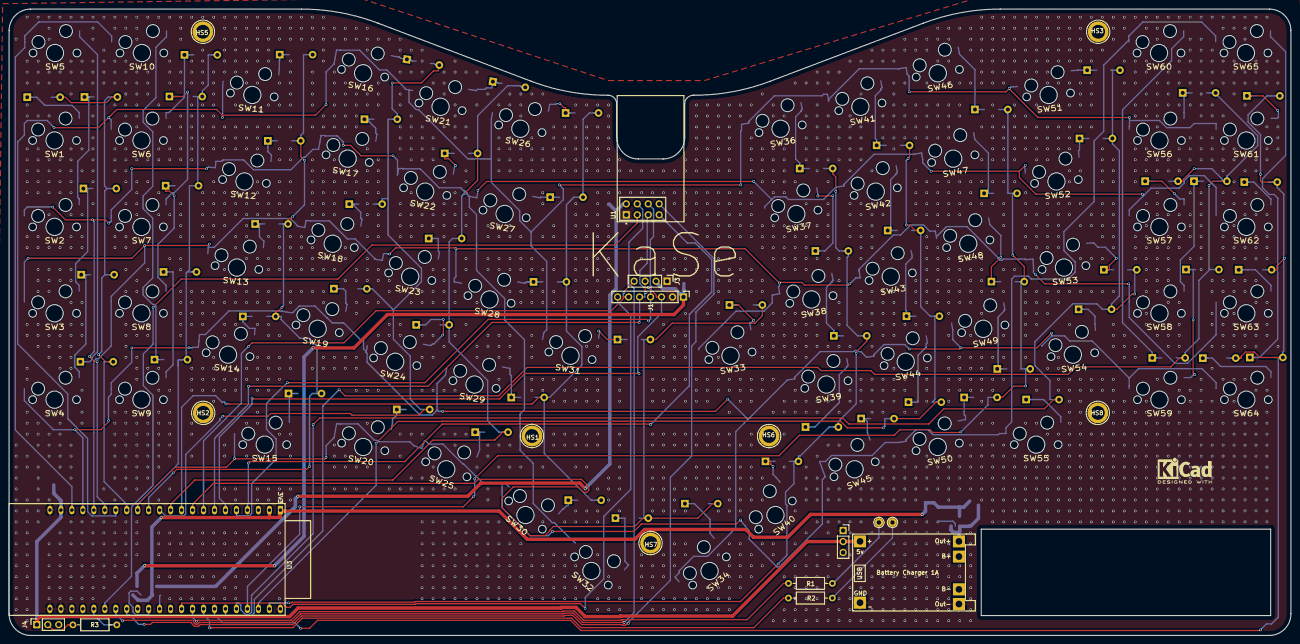
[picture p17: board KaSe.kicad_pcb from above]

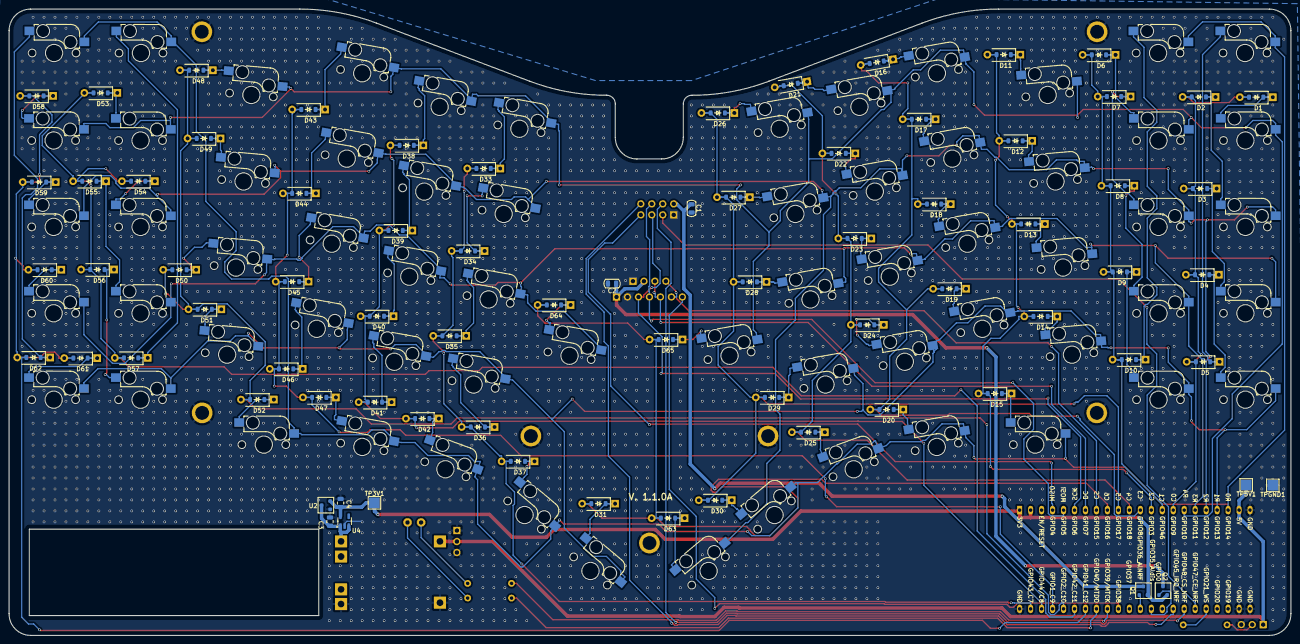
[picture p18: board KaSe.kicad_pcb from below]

Board: 2 copper layers, 296.8 x 145.0 mm, 159 parts (75 on the bottom side), 105 nets.

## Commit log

2024-12-11 send JLC
    [Atreus62-B_Cu.gbl, Atreus62-B_Fab.gbr, Atreus62-B_Mask.gbs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]
2025-04-21 clean up
    [Atreus62.kicad_sch]
2025-05-26 add i2c display ssd1306 and clean up for print
    [Atreus62-2021-03-02-20-39-17.sch, BOM-Atreus62.csv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]
